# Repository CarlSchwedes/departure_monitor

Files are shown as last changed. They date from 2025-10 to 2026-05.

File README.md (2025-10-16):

# Departure Monitor
Day-to-day life in Germany’s capital, Berlin, can be quite chaotic and stressful from time to time.
That’s why a live departure monitor which automatically updates every minute can be an incredibly useful companion — showing you when the next train, bus, subway, or tram will arrive right in front of your house.

I often found myself quite bothered by constantly checking my phones' app to see when the next connection would arrive at my nearest station.
That led to the idea for Departure Monitor - a small DIY device that continuously displays real-time departure data from the public transport system.

With this ESP32-powered gadget, you will have up-to-date information for your preferred station at a glance.

<div style="text-align: center;">
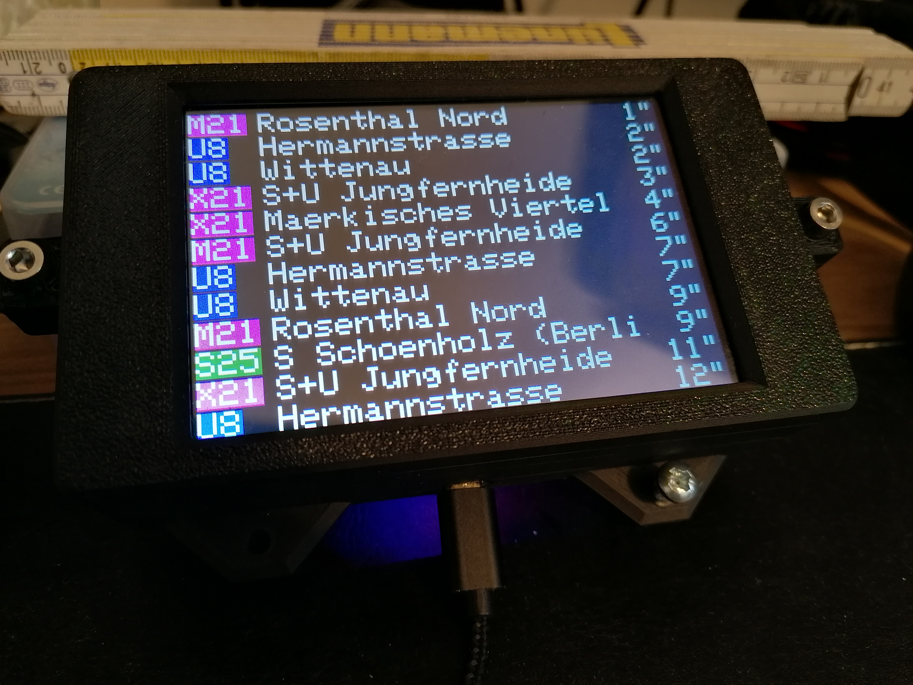
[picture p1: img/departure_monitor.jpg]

</div>

## Features
- Live Updates — Fetches real-time departure data every minute from the public VBB API
- Compact DIY Design — Built around an ESP32 microcontroller and a small display
- Open Source — Includes all models, print files, and source code
- Easy Setup — Simple to assemble and flash using the Arduino IDE
- Configurable — Adjust your station, preferred lines, and directions

# Repository Contents
- Fusion 360 model (.f3d)
- 3D print files (.stl, .3mf for BambuLab)
- Pin configuration and wiring diagram
- Source code for ESP32 (Arduino IDE)
- Images and assembly instructions

## Arduino IDE Setup:
- ArduinoJson 7.4.2
- TFT_eSPI 2.5.43
- ArduinoHttpClient 0.6.1

## TFT_eSPI lib
In ***Arduino\libraries*** path, file structure should look like the following:

TFT_eSPI\ ...
TFT_eSPI\User_Setup_Select.h

TFT_eSPI_Setups\mySetup27_ST7796_ESP32.h

## Pin Configuration
<div style="text-align: center;">
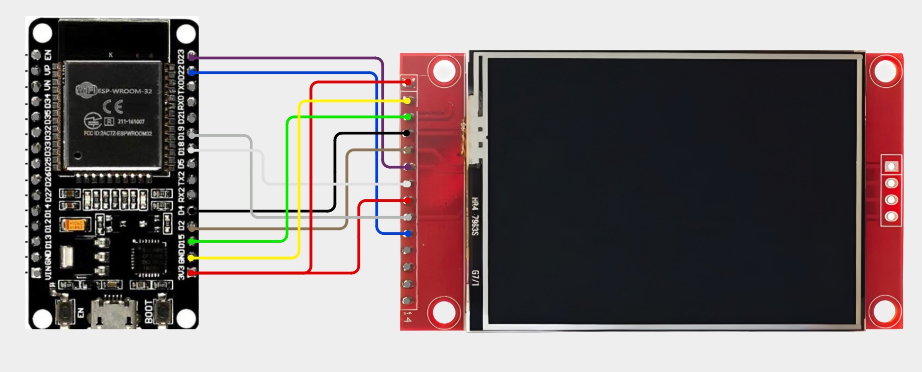
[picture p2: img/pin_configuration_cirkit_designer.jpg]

</div>

## Prepare API URL
Refer to the official [VBB API documentation](https://v6.vbb.transport.rest/api.html) to prepare your user specific api call.

```cpp
#define DEP_LIMIT 20 // define a dept limit, how many entries you want to fetch in one api call (limited to 100/min.)
```

```cpp
String apiURL = "https://v6.vbb.transport.rest/stops/900100003/departures?duration=60&lines=true&results=" + String(DEP_LIMIT);
```

For this api call I used ```GET /stops/:id/departures``` to get all departures at the stop/station.

- ```id: 900100003``` - ***S+U Alexanderplatz*** (https://v6.vbb.transport.rest/stops/900100003/departures)
- ```duration``` - in minutes for the next upcoming departures
- ```lines``` - returns stops/stations along the line when set to ```true```

## Hardware Parts:
- Display: 4" TFT SPI 480x320 ST7796S [display amazon](https://www.amazon.de/dp/B0CQ87KN3Q?ref=ppx_yo2ov_dt_b_fed_asin_title&th=1)

- ESP32 starter kit [esp32 kit amazon](https://www.amazon.de/dp/B0CTMQQ1W4?ref=ppx_yo2ov_dt_b_fed_asin_title)

- jumper cables: [cables short amazon](https://www.amazon.de/dp/B08HQ7K6M7?ref=ppx_yo2ov_dt_b_fed_asin_title)

<div style="text-align: center;">
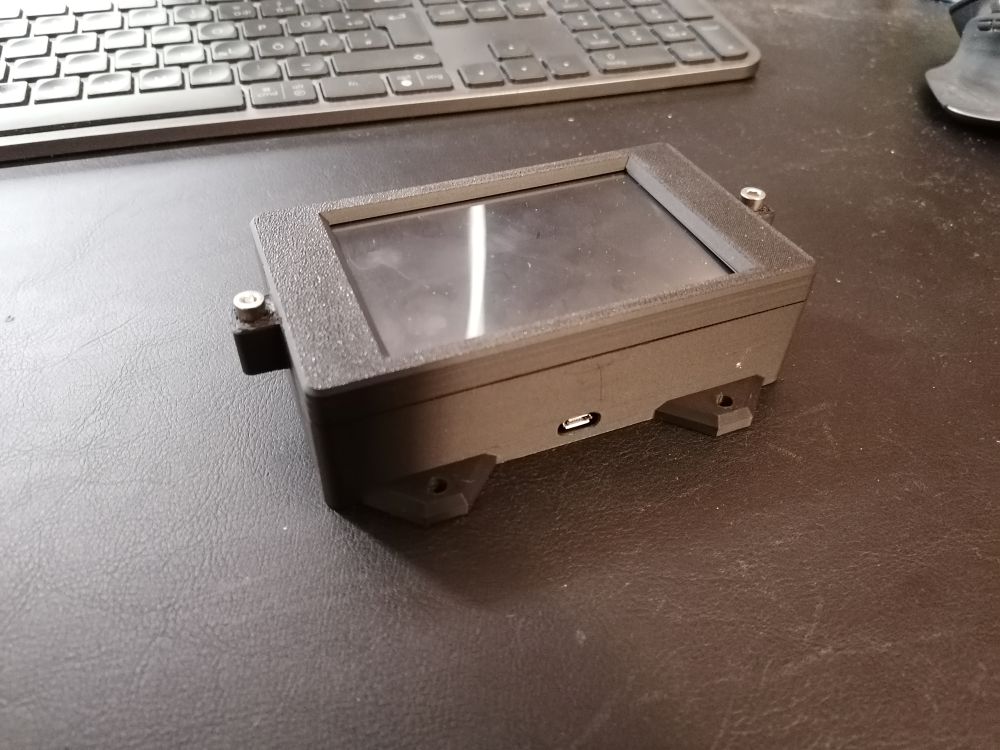
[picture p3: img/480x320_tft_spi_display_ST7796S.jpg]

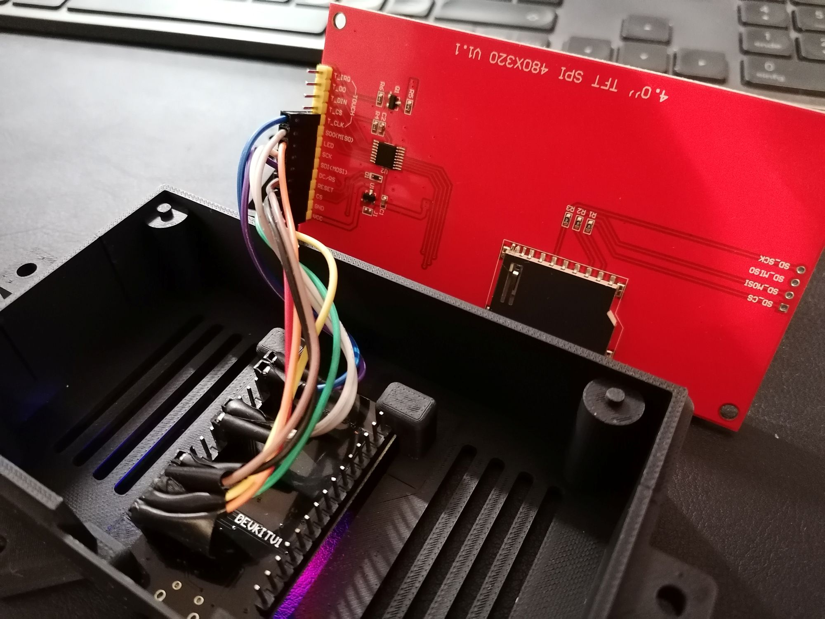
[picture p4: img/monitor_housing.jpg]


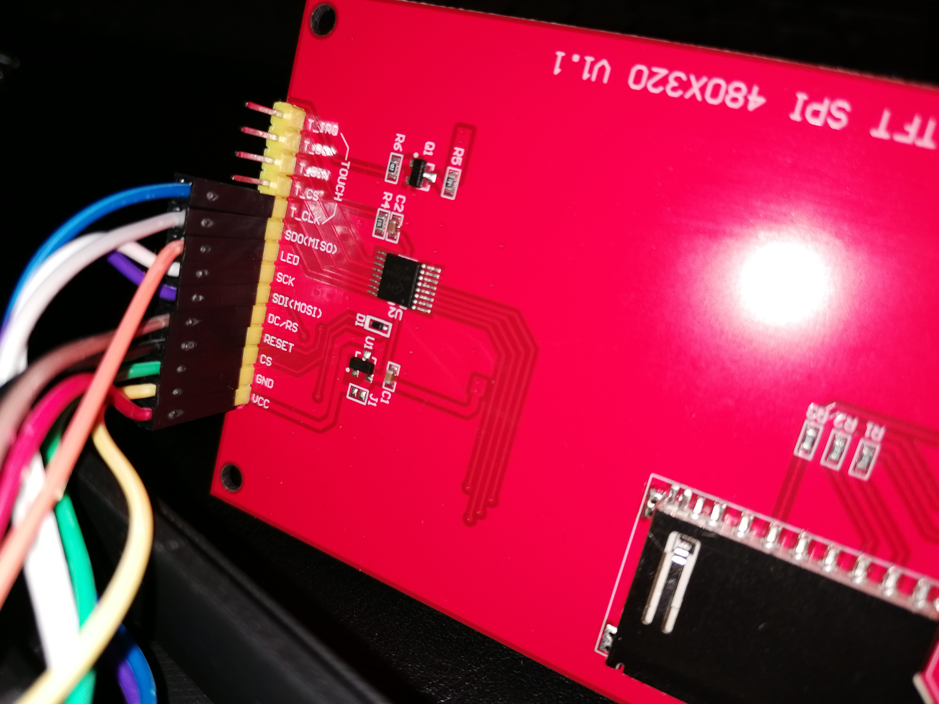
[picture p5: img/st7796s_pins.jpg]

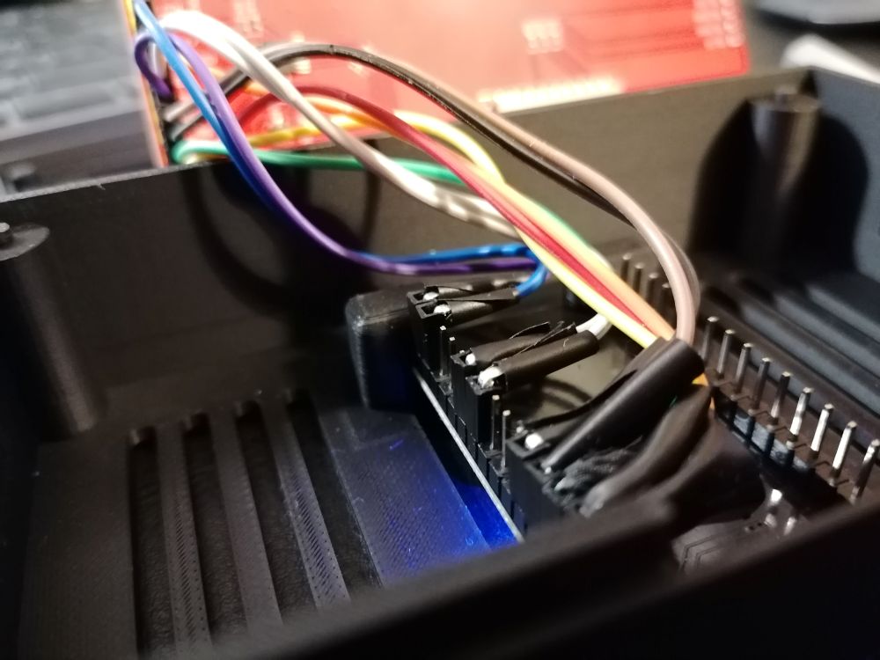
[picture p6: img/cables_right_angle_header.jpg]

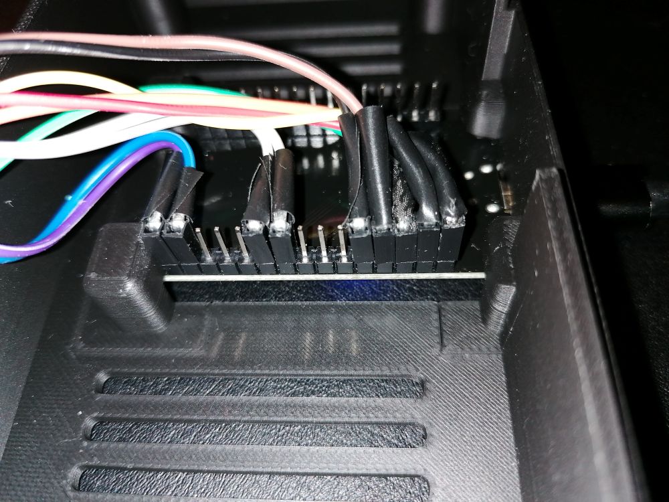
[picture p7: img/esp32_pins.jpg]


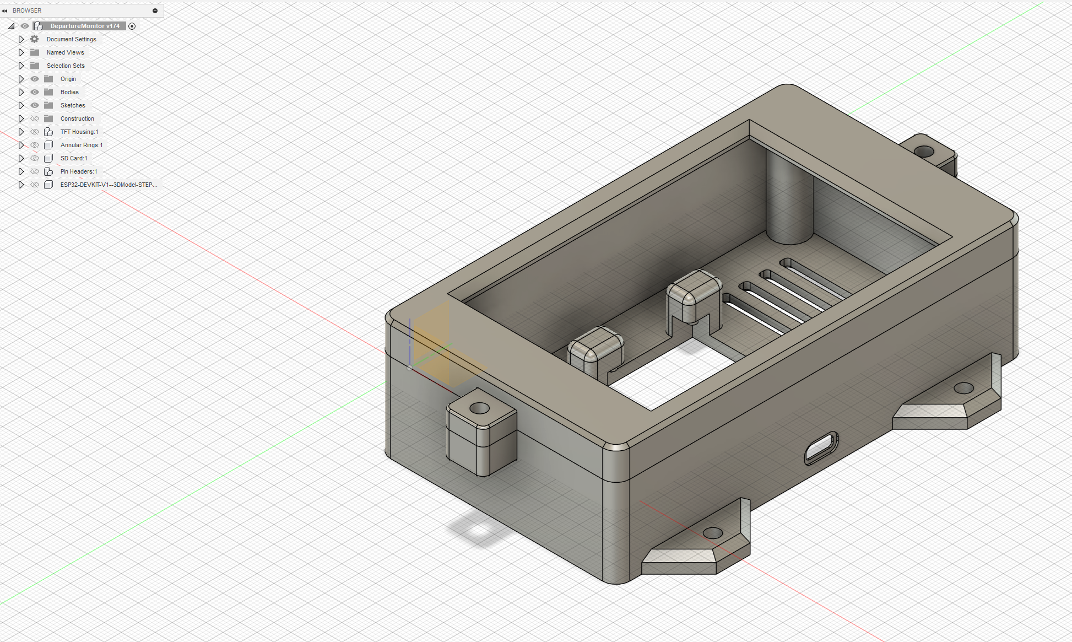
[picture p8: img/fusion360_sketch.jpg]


 The housing has been printed with a bambulab A1 0.4 mm print nozzle and PLA standard filament. Layer height has been set to 0.12 mm which gave appropriate results.
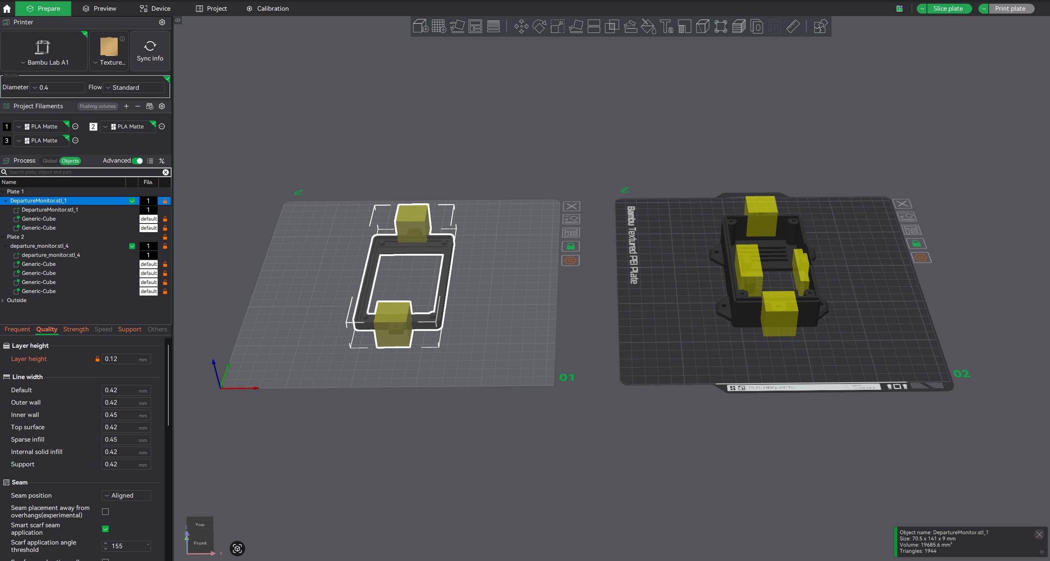
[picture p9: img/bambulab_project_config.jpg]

</div>

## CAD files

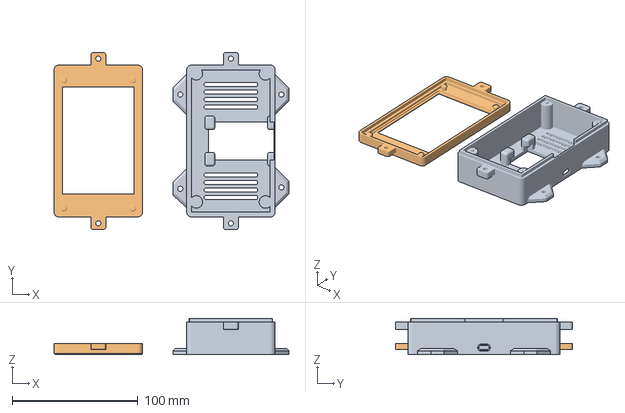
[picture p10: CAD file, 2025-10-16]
model/departure_monitor.3mf
187.0 x 141.0 x 29.0 mm
departure_monitor.stl_4
departure_monitor.stl_1

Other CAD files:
model/departure_monitor.stl

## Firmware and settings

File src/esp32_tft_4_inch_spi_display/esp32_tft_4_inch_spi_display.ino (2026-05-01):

#include <WiFi.h>
#include <WiFiClientSecure.h>
#include <HTTPClient.h>
#include <ArduinoJson.h>
#include <TFT_eSPI.h>
#include <time.h>

#define DEPARTURES_FETCH_LIMIT 20
#define JOURNEYS_FETCH_LIMIT 4
#define JOURNEYS_TRANSFERS_LIMIT 1
#define DEPARTURES_DISPLAY_LIMIT 11
#define JOURNEYS_DISPLAY_LIMIT 1
#define MAX_TRANSFER_TIME 10
#define MIN_TO_ARRIVE_THRESHOLD 3

bool serialPrintForDebugPurpose = false;

unsigned long lastFetchMs = 0UL;
unsigned long lastDisplayMs = 0UL;

// ====== WiFi credentials
const char* ssid = "";
const char* password = "";

// Configurable API endpoints
struct ApiConfig {
  String url;
  size_t jsonCapacity;
  int displayLimit;
};

// VBB API configurations
const ApiConfig apis[] = {
  { "https://v6.vbb.transport.rest/stops/900096458/departures?duration=60&remarks=false&results=" + String(DEPARTURES_FETCH_LIMIT), 32768, DEPARTURES_DISPLAY_LIMIT },  // departures
  { "https://v6.vbb.transport.rest/journeys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" + String(JOURNEYS_TRANSFERS_LIMIT) + "&via=900009203&remarks=false&verkehrsunternehmen=false&polyline=false&language=en&format=compact&results=" + String(JOURNEYS_FETCH_LIMIT), 65536, JOURNEYS_DISPLAY_LIMIT }  // journeys
};

const int NUM_APIS = sizeof(apis) / sizeof(apis[0]);

// Global data storage (fetched once per loop)
struct ApiData {
  int status = 0;                     // 1=valid, 0=fetch-ok, -1=json, -2=http
  bool stale = false;
  int httpErrorCode = 0;              // http status
  DynamicJsonDocument* temp = nullptr;
  DynamicJsonDocument* doc = nullptr;
  unsigned long lastSuccessMs = 0UL;
  bool INIT_FETCH_VALID = false;
};

ApiData apiData[NUM_APIS] = {};

TFT_eSPI tft = TFT_eSPI();

// Helper: Parse ISO string -> time_t
time_t parseIsoToTime(const String& isoTimeStr) {
  if (isoTimeStr.length() < 19) return (time_t)-1;
  
  struct tm t = {0};
  t.tm_year  = isoTimeStr.substring(0, 4).toInt() - 1900;
  t.tm_mon   = isoTimeStr.substring(5, 7).toInt() - 1;
  t.tm_mday  = isoTimeStr.substring(8, 10).toInt();
  t.tm_hour  = isoTimeStr.substring(11, 13).toInt();
  t.tm_min   = isoTimeStr.substring(14, 16).toInt();
  t.tm_sec   = isoTimeStr.substring(17, 19).toInt();
  t.tm_isdst = -1;
  
  return mktime(&t);
}


String timeToIsoString(time_t t) {
  struct tm tmTime;
  localtime_r(&t, &tmTime);

  char buf[25];  // "2026-04-24T13:05:00"
  strftime(buf, sizeof(buf), "%Y-%m-%iT%H:%M:%S", &tmTime);
  return String(buf);
}


// Get current time as time_t (cached)
time_t getCurrentTime() {
  struct tm nowTm;
  if (!getLocalTime(&nowTm)) {
    Serial.println("Failed to get current time");
    return (time_t)-999;
  }
  return mktime(&nowTm);
}


// Minutes from now -> target time
int getMinutesToDeparture(const String& isoTimeStr) {
  time_t arrival = parseIsoToTime(isoTimeStr);
  if (arrival < 0) return -999;
  
  time_t now = getCurrentTime();
  if (now < 0) return -999;
  
  return round(difftime(arrival, now) / 60.0);
}


// Minutes between two times
int getMinutesBetween(const String& startIsoStr, const String& endIsoStr) {
  time_t start = parseIsoToTime(startIsoStr);
  time_t end   = parseIsoToTime(endIsoStr);
  
  if (start < 0 || end < 0) return -999;
  
  return round(difftime(end, start) / 60.0);
}


String decodeUtf8(String input) {
  input.replace("\u00e4", "ae");
  input.replace("\u00f6", "oe");
  input.replace("\u00fc", "ue");
  input.replace("\u00c4", "Ae");
  input.replace("\u00d6", "Oe");
  input.replace("\u00dc", "Ue");
  input.replace("\u00df", "ss");

  for (int i = 0; i < input.length(); i++) {
    if (input[i] < 32 || input[i] > 126) input[i] = '?';
  }

  return input;
}


uint16_t getBackgroundColor(String product) {
  uint16_t color = TFT_BLACK;

  if (product == "bus")
    color = TFT_MAGENTA;
  else if (product == "suburban")
    color = TFT_DARKGREEN;
  else if (product == "subway")
    color = TFT_BLUE;
  else if (product == "tram")
    color = TFT_RED;
  else if (product == "ferry")
    color = TFT_SKYBLUE;

  return color;
} 


void showCountdownMessage(int seconds, const char* message) {
  for (int i = seconds; i >= 0; i--) {
    tft.fillRect(tft.width() / 4, tft.height() / 4, tft.width() * 3 / 4, tft.height() * 3 / 4, TFT_BLACK);
    String msg = String(message) + " " + String(i) + " sec...";
    tft.setTextColor(TFT_RED, TFT_BLACK);
    tft.setTextDatum(MC_DATUM);
    tft.drawString(msg, tft.width() / 2, tft.height() / 2);
    delay(1000);
  }
}


void displayError(const char* message) {
  tft.fillScreen(TFT_BLACK);
  tft.setTextSize(1);
  tft.setCursor(0, 0);
  tft.setTextColor(TFT_RED, TFT_BLACK);
  tft.println("Error:");
  tft.println(message);

  showCountdownMessage(3, "Restart in");
}


void displayWiFiOk() {
  tft.fillScreen(TFT_BLACK);
  tft.setTextSize(1);
  tft.setCursor(0, 0);
  tft.setTextColor(TFT_WHITE, TFT_BLACK);
  tft.println("WiFi Ok!");

  showCountdownMessage(10, "Loop over in");
}


void cleanupApiData(int i) {
    apiData[i].status = 0;
    apiData[i].stale = false;
    apiData[i].httpErrorCode = 0;
    apiData[i].INIT_FETCH_VALID = false;
    apiData[i].lastSuccessMs = 0UL;
    if (apiData[i].doc) {
      delete apiData[i].doc;
      apiData[i].doc = nullptr;
    }
    if (apiData[i].temp) {
      delete apiData[i].temp;
      apiData[i].temp = nullptr;
    }
}


template <typename... Args>
void serialPrintfDebug(const char* dbgMsg, Args... args) {
  if (serialPrintForDebugPurpose) {
    Serial.printf(dbgMsg, args...);
  }
}


void handleApiError(int apiIndex, int apiStatus, HTTPClient& http, WiFiClientSecure& client, int delayMs = 100) {
  serialPrintfDebug<int, int>("\t\t ERROR: API<%i> failed to fetch; STATUS: %i\n", apiIndex, apiStatus);
  apiData[apiIndex].status = apiStatus;
  http.end();
  client.stop();
  delay(delayMs);
}


// Fetch ALL APIs -> store in global apiData[]
void fetchApiData() {
  serialPrintfDebug("Fetching...\n");
  for (int i = 0; i < NUM_APIS; i++) {
    serialPrintfDebug<int>("API: %i\n", i);

    if (WiFi.status() != WL_CONNECTED) {
      WiFi.reconnect();
      delay(2000);
      if (WiFi.status() != WL_CONNECTED) 
        serialPrintfDebug("Failed to reconnect WiFi, restart!\n");
        ESP.restart();
    }

    for (int attempt = 0; attempt <= 2; attempt++) {
      serialPrintfDebug<int>("\t ATTEMPT: %i\n", attempt);

      // Fresh client EVERY TIME
      WiFiClientSecure client;
      client.setInsecure();
      client.setTimeout(10000);
      
      HTTPClient http;
      http.useHTTP10(true); // use HTTP/1.0 instead of default HTTP/1.1; HTTP/1.0 avoids trying to keep socket alive -> client typically sends Connection: close
      http.setReuse(false); // HTTPClient forced not to reuse TCP connection for next request; reduces bugs where ESP32 accidentally reuses a stale or wrong connection
      http.begin(client, apis[i].url);
      http.addHeader("User-Agent", "ESP32-Display/1.0");
      http.setTimeout(10000);

      unsigned long t = millis();
      int httpCode = http.GET();
      apiData[i].httpErrorCode = httpCode;
      serialPrintfDebug<unsigned long>("\t http.GET() took %lu ms\n", millis() - t);
      yield();  // Keep connection alive; prevents ESP32 watchdog resets
      serialPrintfDebug<int>("\t HTTP-Code GET: %i\n", httpCode);

      // ERROR Handling
      if (httpCode != HTTP_CODE_OK) {
        handleApiError(i, -2, http, client);
        continue;
      }

      t = millis();
      String payload = http.getString();
      serialPrintfDebug<unsigned long>("\t http.getString() took %lu ms\n", millis() - t);
      //yield();  // Keep connection alive; prevents ESP32 watchdog resets
      serialPrintfDebug<int>("\t Payload bytes: %i\n", payload.length());
      serialPrintfDebug<int>("\t Expected bytes: %i\n", http.getSize());
      serialPrintfDebug<const char*>("\t Payload preview: %.60s\n", payload.c_str());
      
      // ERROR Handling
      if (payload.length() == 0) {
        serialPrintfDebug("\t\t ERROR: Empty payload (EmptyInput likely)\n");
        handleApiError(i, -1, http, client);
        continue;
      }

      // ERROR Handling
      if (payload[0] != '{' && payload[0] != '[') {
        serialPrintfDebug("\t\t ERROR: Payload JSON must start with '{' or '['\n");
        handleApiError(i, -1, http, client);
        continue;
      }

      apiData[i].temp = new DynamicJsonDocument(apis[i].jsonCapacity);
      DeserializationError error = deserializeJson(*apiData[i].temp, payload);

      if (error) {
        serialPrintfDebug<const char*>("\t ERROR: deserializeJson: %s\n", error.c_str());
        handleApiError(i, -1, http, client);
        continue;
      }

      if (serialPrintForDebugPurpose && !error) {
        String preview;
        serializeJson(*apiData[i].temp, preview);
        serialPrintfDebug<const char*>("\t JSON preview: %.60s\n", preview.c_str());
        serialPrintfDebug<int>("\t JSON length: %i\n", preview.length());
      }

      apiData[i].status = 0;
      serialPrintfDebug<int>("\t Status-Code: %i\n", apiData[i].status);

      http.end();
      client.stop();

      delay(500);
      break;
    }
  }
}


bool validateDeparturesDoc(DynamicJsonDocument& doc) {
  serialPrintfDebug("\t Validating departures...\n");
    if (doc.isNull()) {
    serialPrintfDebug("\t ERROR: DynamicJsonDocument doc is NULL\n");
    return false;
  }

  if (!doc["departures"].is<JsonArray>()) {
    serialPrintfDebug("\t ERROR: Departures not of type <JsonArray>\n");
    return false;
  }

  JsonArray deps = doc["departures"].as<JsonArray>();
  if (deps.isNull()) {
    serialPrintfDebug("\t ERROR: Departures <JsonArray> is NULL\n");
    return false;
  }
  
  if (deps.size() == 0) {
    serialPrintfDebug("\t ERROR: Departures <JsonArray> size 0\n");
    return false;
  }

  JsonObject first = deps[0];
  if (first.isNull()) {
    serialPrintfDebug("\t ERROR: Departures <JsonObject> deps[0] is NULL\n");
    return false;
  }
  if (!first["when"].is<const char*>()) {
    serialPrintfDebug("\t ERROR: Departures <JsonObject> deps[0][\"when\"] is not of type <const char*>\n");
    return false;
  }
  if (!first["line"]["name"].is<const char*>()) {
    serialPrintfDebug("\t ERROR: Departures <JsonObject> deps[0][\"line\"][\"name\"] is not of type <const char*>\n");
    return false;
  }
  if (!first["direction"].is<const char*>()) {
    serialPrintfDebug("\t ERROR: Departures <JsonObject> deps[0][\"direction\"] is not of type <const char*>\n");
    return false;
  }

  return true;
}


bool validateJourneysDoc(DynamicJsonDocument& doc) {
  serialPrintfDebug("\t Validating journeys...\n");
  if (doc.isNull()) {
    serialPrintfDebug("\t ERROR: DynamicJsonDocument doc is NULL\n");
    return false;
  }

  if (!doc["journeys"].is<JsonArray>()) {
    serialPrintfDebug("\t ERROR: Journeys not of type <JsonArray>\n");
    return false;
  }

  JsonArray journeys = doc["journeys"].as<JsonArray>();
  if (journeys.isNull()) {
    serialPrintfDebug("\t ERROR: Journeys <JsonArray> is NULL\n");
    return false;
  }
  if (journeys.size() == 0) {
    serialPrintfDebug("\t ERROR: Journeys <JsonArray> size 0\n");
    return false;
  }

  JsonObject first = journeys[0];
  if (first.isNull()) {
    serialPrintfDebug("\t ERROR: Journeys <JsonObject> journeys[0] is NULL\n");
    return false;
  }
  if (!first["legs"].is<JsonArray>()) {
    serialPrintfDebug("\t ERROR: Journeys <JsonObject> journeys[0][\"legs\"] is not of type <JsonArray>\n");
    return false;
  }

  JsonArray legs = first["legs"].as<JsonArray>();
  if (legs.size() < 1) {
    serialPrintfDebug("\t ERROR: Journeys journeys[0][\"legs\"] size 0\n");
    return false;
  }

  return true;
}


bool validateApiDoc(int apiIndex, DynamicJsonDocument& doc) {
  switch (apiIndex) {
    case 0: return validateDeparturesDoc(doc);
    case 1: return validateJourneysDoc(doc);
    default: return false;
  }
}


void validateApiData() {
  serialPrintfDebug("Validating...\n");
  for (int i = 0; i < NUM_APIS; i++) {

    if (i == 0 && apiData[i].status == 0 && serialPrintForDebugPurpose) {
      JsonArray deps = (*apiData[0].temp)["departures"].as<JsonArray>();
      String preview;
      serializeJson(deps, preview);
      serialPrintfDebug<int, int, const char*>("\t DOC<%i>: %i items: %.80s\n", i, deps.size(), preview.c_str());
    }
    if (i == 1 && apiData[i].status == 0 && serialPrintForDebugPurpose) {
      JsonArray jrny = (*apiData[1].temp)["journeys"].as<JsonArray>();
      String preview;
      serializeJson(jrny, preview);
      serialPrintfDebug<int, int, const char*>("\t DOC<%i>: %i items: %.80s\n", i, jrny.size(), preview.c_str());
    }

    if (apiData[i].status == 0 && validateApiDoc(i, (*apiData[i].temp))) {
      apiData[i].INIT_FETCH_VALID = true;
      apiData[i].status = 1;
      delete apiData[i].doc;
      apiData[i].doc = new DynamicJsonDocument(*apiData[i].temp);

      delete apiData[i].temp;
      apiData[i].temp = nullptr;
      apiData[i].lastSuccessMs = millis(); // set age of successful fetch to current time

      if (i == 0 && serialPrintForDebugPurpose) {
        JsonArray deps = (*apiData[0].doc)["departures"].as<JsonArray>();
        String preview;
        serializeJson(deps, preview);
        serialPrintfDebug<int, int, const char*>("\t\t DOC<%i>: %i items: %.80s\n", i, deps.size(), preview.c_str());
      }
      if (i == 1 && serialPrintForDebugPurpose) {
        JsonArray journeys = (*apiData[1].doc)["journeys"].as<JsonArray>();
        String preview;
        serializeJson(journeys, preview);
        serialPrintfDebug<int, int, const char*>("\t\t DOC<%i>: %i items: %.80s\n", i, journeys.size(), preview.c_str());
      }

      serialPrintfDebug<int>("\t API<%i> Valid Json; LastSuccess: %lu ms\n", i, apiData[i].lastSuccessMs);
    }
    else {
      delete apiData[i].temp;
      apiData[i].temp = nullptr;
      serialPrintfDebug<int>("\t API<%i> Invalid Json; LastSuccess: %lu ms; Age: %i ms\n", i, apiData[i].lastSuccessMs, millis() - apiData[i].lastSuccessMs);
    }
    serialPrintfDebug("\t --------\n");
  }
}


void staleJsonDeparturesDoc(unsigned long ageMs) {
  JsonArray deps = (*apiData[0].doc)["departures"].as<JsonArray>();

  serialPrintfDebug("\t\t Adjusted mins: ");
  for (JsonObject dep : deps) {
    time_t correctedTime = parseIsoToTime(dep["when"].as<String>()) - (ageMs / 60000);
    dep["when"] = timeToIsoString(correctedTime);

    serialPrintfDebug("depWhen: %s\n", dep["when"].as<String>());

    serialPrintfDebug<int>("%i ", getMinutesToDeparture(dep["when"].as<String>()));
  }
  serialPrintfDebug("\n");
}


void staleJsonJourneysDoc(unsigned long ageMs) {
  JsonArray journeys = (*apiData[1].doc)["journeys"].as<JsonArray>();

  serialPrintfDebug("\t\t Adjusted mins: ");
  for (JsonObject jrny : journeys) {
    time_t correctedTime = parseIsoToTime(jrny["legs"][0]["departure"].as<String>()) - (ageMs / 60000);
    jrny["legs"][0]["departure"] = timeToIsoString(correctedTime);

    serialPrintfDebug("jrnyLegsDepartures: %s\n", jrny["legs"][0]["departure"].as<String>());

    serialPrintfDebug<int>("%i ", getMinutesToDeparture(jrny["legs"][0]["departure"].as<String>()));
  }
  serialPrintfDebug("\n");
}


void handleStaleJSON() {
  serialPrintfDebug("Handling stale json...\n");
  for (int i = 0; i < NUM_APIS; i++) {
    if (apiData[i].INIT_FETCH_VALID) {
      unsigned long ageMs = millis() - apiData[i].lastSuccessMs;

      serialPrintfDebug<int, int>("\t API<%i>-STATUS: %i\n", i, apiData[i].status);
      serialPrintfDebug<unsigned long>("\t\t age: %lu\n", ageMs);

      if (apiData[i].status != 1 && ageMs > 60000 && ageMs < 180000) { // handle stale json data (of current invalid fetch)
        apiData[i].stale = true;
        serialPrintfDebug("\t\t Updating with STALE-JSON...\n");
        //if (i == 0) staleJsonDeparturesDoc(ageMs);
        //if (i == 1) staleJsonJourneysDoc(ageMs);
      }
      else if (ageMs > 180000) {
        ESP.restart();  // Instant full reset
        //cleanupApiData(i);
        //serialPrintfDebug("\t\t Cleaned and reseted API struct from outdated JSON!\n");
      }
      else if (apiData[i].status == 1) {
        apiData[i].stale = false;
        serialPrintfDebug("\t\t Object not stale. Continue...\n");
      }
    }
  }
}


// Display DEPARTURES (API 0)
void displayDepartures() {

  if (!apiData[0].doc) {
    tft.println("No departures ...");
    return;
  }
  
  JsonArray deps = (*apiData[0].doc)["departures"];
  serialPrintfDebug<int>("\t -> Departures array size: %i\n", deps.size());  // Debug!
  
  // if (deps.isNull()) return;
  
  // if (deps.isNull() || deps.size() == 0) {
  //   tft.println("No departures found ...");
  //   return;
  // }

  uint16_t tft_color = apiData[0].stale ? TFT_LIGHTGREY : TFT_WHITE;

  int count = 0;
  for (JsonObject dep : deps) {
    if (count >= apis[0].displayLimit) break;
    
    String line = dep["line"]["name"].as<String>();
    String direction = dep["direction"].as<String>();
    String product = dep["line"]["product"].as<String>();
    int min_to_arrive = getMinutesToDeparture(dep["when"].as<String>());
    
    if (min_to_arrive < MIN_TO_ARRIVE_THRESHOLD) continue;
    
    uint16_t bg = getBackgroundColor(product);
    tft.setTextColor(TFT_WHITE, bg);
    tft.drawString(line, 0, count * (tft.fontHeight() + 3));
    
    direction = decodeUtf8(direction).substring(0, 19);
    while (direction.length() < 19) direction += " ";
    
    String delta = (min_to_arrive <= 0) ? "now" : String(min_to_arrive) + "'";
    while (delta.length() < 4) delta = " " + delta;
    
    tft.setTextColor(tft_color, TFT_BLACK);
    tft.drawString(direction + delta, 65, count * (tft.fontHeight() + 3));
    count++;
  }
  
  if (count == 0) tft.println("No departures ...");
}


// Display JOURNEYS (API 1)
void displayJourneys() {
  int count = DEPARTURES_DISPLAY_LIMIT;
  // draw thin separator line
  tft.drawLine(0, (count * (tft.fontHeight() + 3)) - 2, tft.width() - 1, (count * (tft.fontHeight() + 3)) - 2, TFT_WHITE);

  if (!apiData[1].doc) {
    tft.drawString("No journeys data ...", 0, DEPARTURES_DISPLAY_LIMIT * (tft.fontHeight() + 3));
    return;
  }
  
  JsonArray journeys = (*apiData[1].doc)["journeys"];
  serialPrintfDebug<int>("\t -> Journeys array size: %i\n", journeys.size());  // Debug!

  // if (journeys.isNull() || journeys.size() == 0) {
  //   tft.drawString("No journeys found ...", 0, DEPARTURES_DISPLAY_LIMIT * (tft.fontHeight() + 3));
  //   return;
  // }

  uint16_t tft_color = apiData[1].stale ? TFT_LIGHTGREY : TFT_WHITE;

  for (JsonObject jrny : journeys) {

    String line0 = jrny["legs"][0]["line"]["name"].as<String>();
    String direction0 = "HER";
    String product0 = jrny["legs"][0]["line"]["product"].as<String>();

    String line2 = jrny["legs"][2]["line"]["name"].as<String>();
    String destination = jrny["legs"][2]["destination"]["name"].as<String>();
    String product2 = jrny["legs"][2]["line"]["product"].as<String>();

    int min_to_arrive = getMinutesToDeparture(jrny["legs"][0]["departure"].as<String>());
    int transfer_time = getMinutesBetween(jrny["legs"][0]["arrival"].as<String>(), jrny["legs"][2]["departure"].as<String>());

    uint16_t background0 = getBackgroundColor(product0);
    uint16_t background2 = getBackgroundColor(product2);

    if (min_to_arrive >= MIN_TO_ARRIVE_THRESHOLD && transfer_time <= MAX_TRANSFER_TIME) {
      tft.setTextColor(TFT_WHITE, background0);
      tft.drawString(line0, 0, count * (tft.fontHeight() + 3));
      direction0 += " -> ";

      tft.setTextColor(TFT_WHITE, background2);
      tft.drawString(line2, 190, count * (tft.fontHeight() + 3));
      if (destination.length() > 8) destination = destination.substring(0, 8);

      while ((direction0.length()+line2.length()+destination.length()) < 17) destination += " ";

      String delta_time = (min_to_arrive == 0) ? "now" : String(min_to_arrive) + "\'";
      while (delta_time.length() < 4) delta_time = " " + delta_time;

      String description = decodeUtf8(direction0);
      tft.setTextColor(tft_color, TFT_BLACK);
      tft.drawString(description, 65, count * (tft.fontHeight() + 3));

      description = decodeUtf8(destination) + delta_time;
      tft.setTextColor(tft_color, TFT_BLACK);
      tft.drawString(description, 260, count * (tft.fontHeight() + 3));

      count++;
    }

    if (count >= (DEPARTURES_DISPLAY_LIMIT+1)) 
      break;
  }

  if (count == DEPARTURES_DISPLAY_LIMIT) {
    tft.setTextColor(TFT_WHITE, TFT_BLACK);
    tft.drawString("No journeys at the time ...", 0, count * (tft.fontHeight() + 3));
  }
}


// Display ALL data (calls individual displays)
void displayAllData() {
  tft.fillScreen(TFT_BLACK);
  tft.setTextDatum(TL_DATUM);
  tft.setTextSize(3);
  tft.setCursor(0, 0);

  serialPrintfDebug("Displaying...\n");

  displayDepartures();
  displayJourneys();
}
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
void loop() {
  unsigned long now = millis();
  
  // Fetch APIs every 30s
  if (now - lastFetchMs >= 30000) {
    fetchApiData();    // Fetch ALL APIs once
    validateApiData(); // Validate JSON objects
    handleStaleJSON(); // In case fetch failed
    lastFetchMs = now;
  }
  
  // Redraw every 60s (uses latest data)
  if (now - lastDisplayMs >= 60000) {
    displayAllData();  // Display everything
    lastDisplayMs = now;
  }
  
  serialPrintfDebug<int, int, int>("\nFree heap: %d/%d; [%d%% usage]\n", ESP.getFreeHeap(), ESP.getHeapSize(), (1.0-(ESP.getFreeHeap()/(float)ESP.getHeapSize()))*100.0);
  serialPrintfDebug("--------\n");

  delay(15000);
}

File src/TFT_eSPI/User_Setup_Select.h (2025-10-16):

// This header file contains a list of user setup files and defines which one the
// compiler uses when the IDE performs a Verify/Compile or Upload.
//
// Users can create configurations for different boards and TFT displays.
// This makes selecting between hardware setups easy by "uncommenting" one line.

// The advantage of this hardware configuration method is that the examples provided
// with the library should work with immediately without any other changes being
// needed. It also improves the portability of users sketches to other hardware
// configurations and compatible libraries.
//
// Create a shortcut to this file on your desktop to permit quick access for editing.
// Re-compile and upload after making and saving any changes to this file.

// Example User_Setup files are stored in the "User_Setups" folder. These can be used
// unmodified or adapted for a particular hardware configuration.

#ifndef USER_SETUP_LOADED //  Lets PlatformIO users define settings in
                          //  platformio.ini, see notes in "Tools" folder.

///////////////////////////////////////////////////////
//   User configuration selection lines are below    //
///////////////////////////////////////////////////////

// Only ONE line below should be uncommented to define your setup.  Add extra lines and files as needed.

//#include <User_Setup.h>           // Default setup is root library folder
#include <../TFT_eSPI_Setups/mySetup27_ST7796_ESP32.h>           // Default setup is root library folder


//#include <User_Setups/Setup1_ILI9341.h>  // Setup file for ESP8266 configured for my ILI9341
//#include <User_Setups/Setup2_ST7735.h>   // Setup file for ESP8266 configured for my ST7735
//#include <User_Setups/Setup3_ILI9163.h>  // Setup file for ESP8266 configured for my ILI9163
//#include <User_Setups/Setup4_S6D02A1.h>  // Setup file for ESP8266 configured for my S6D02A1
//#include <User_Setups/Setup5_RPi_ILI9486.h>        // Setup file for ESP8266 configured for my stock RPi TFT
//#include <User_Setups/Setup6_RPi_Wr_ILI9486.h>     // Setup file for ESP8266 configured for my modified RPi TFT
//#include <User_Setups/Setup7_ST7735_128x128.h>     // Setup file for ESP8266 configured for my ST7735 128x128 display
//#include <User_Setups/Setup8_ILI9163_128x128.h>    // Setup file for ESP8266 configured for my ILI9163 128x128 display
//#include <User_Setups/Setup9_ST7735_Overlap.h>     // Setup file for ESP8266 configured for my ST7735
//#include <User_Setups/Setup10_RPi_touch_ILI9486.h> // Setup file for ESP8266 configured for ESP8266 and RPi TFT with touch

//#include <User_Setups/Setup11_RPi_touch_ILI9486.h> // Setup file configured for ESP32 and RPi TFT with touch
//#include <User_Setups/Setup12_M5Stack_Basic_Core.h>// Setup file for the ESP32 based M5Stack (Basic Core only)
//#include <User_Setups/Setup13_ILI9481_Parallel.h>  // Setup file for the ESP32 with parallel bus TFT
//#include <User_Setups/Setup14_ILI9341_Parallel.h>  // Setup file for the ESP32 with parallel bus TFT
//#include <User_Setups/Setup15_HX8357D.h>           // Setup file for ESP8266 configured for HX8357D
//#include <User_Setups/Setup16_ILI9488_Parallel.h>  // Setup file for the ESP32 with parallel bus TFT
//#include <User_Setups/Setup17_ePaper.h>            // Setup file for ESP8266 and any Waveshare ePaper display
//#include <User_Setups/Setup18_ST7789.h>            // Setup file for ESP8266 configured for ST7789

//#include <User_Setups/Setup19_RM68140_Parallel.h>	 // Setup file configured for RM68140 with parallel bus

//#include <User_Setups/Setup20_ILI9488.h>           // Setup file for ESP8266 and ILI9488 SPI bus TFT
//#include <User_Setups/Setup21_ILI9488.h>           // Setup file for ESP32 and ILI9488 SPI bus TFT

//#include <User_Setups/Setup22_TTGO_T4.h>           // Setup file for ESP32 and TTGO T4 version 1.2
//#include <User_Setups/Setup22_TTGO_T4_v1.3.h>      // Setup file for ESP32 and TTGO T4 version 1.3
//#include <User_Setups/Setup23_TTGO_TM.h>           // Setup file for ESP32 and TTGO TM ST7789 SPI bus TFT
//#include <User_Setups/Setup24_ST7789.h>            // Setup file for DSTIKE/ESP32/ESP8266 configured for ST7789 240 x 240
//#include <User_Setups/Setup25_TTGO_T_Display.h>    // Setup file for ESP32 and TTGO T-Display ST7789V SPI bus TFT
//#include <User_Setups/Setup26_TTGO_T_Wristband.h>  // Setup file for ESP32 and TTGO T-Wristband ST7735 SPI bus TFT

//#include <User_Setups/Setup27_RPi_ST7796_ESP32.h>    // ESP32   RPi MHS-4.0 inch Display-B
//#include <User_Setups/Setup28_RPi_ST7796_ESP8266.h>  // ESP8266 RPi MHS-4.0 inch Display-B

//#include <User_Setups/Setup29_ILI9341_STM32.h>          // Setup for Nucleo board
//#include <User_Setups/Setup30_ILI9341_Parallel_STM32.h> // Setup for Nucleo board and parallel display
//#include <User_Setups/Setup31_ST7796_Parallel_STM32.h>  // Setup for Nucleo board and parallel display
//#include <User_Setups/Setup32_ILI9341_STM32F103.h>      // Setup for "Blue/Black Pill"

//#include <User_Setups/Setup33_RPi_ILI9486_STM32.h>      // Setup for Nucleo board

//#include <User_Setups/Setup34_ILI9481_Parallel_STM32.h> // Setup for Nucleo board and parallel display
//#include <User_Setups/Setup35_ILI9341_STM32_Port_Bus.h> // Setup for STM32 port A parallel display

//#include <User_Setups/Setup36_RPi_touch_ST7796.h>      // Setup file configured for ESP32 and RPi ST7796 TFT with touch

//#include <User_Setups/Setup42_ILI9341_ESP32.h>           // Setup file for ESP32 and SPI ILI9341 240x320
//#include <User_Setups/Setup43_ST7735.h>            // Setup file for ESP8266 & ESP32 configured for my ST7735S 80x160
//#include <User_Setups/Setup44_TTGO_CameraPlus.h>   // Setup file for ESP32 and TTGO T-CameraPlus ST7789 SPI bus TFT    240x240
//#include <User_Setups/Setup45_TTGO_T_Watch.h>      // Setup file for ESP32 and TTGO T-Watch ST7789 SPI bus TFT  240x240
//#include <User_Setups/Setup46_GC9A01_ESP32.h>      // Setup file for ESP32 and GC9A01 SPI bus TFT  240x240

//#include <User_Setups/Setup47_ST7735.h>            // Setup file for ESP32 configured for ST7735 128 x 128 animated eyes

//#include <User_Setups/Setup50_SSD1963_Parallel.h>  // Setup file for ESP32 and SSD1963 TFT display

//#include <User_Setups/Setup51_LilyPi_ILI9481.h>    // Setup file for LilyGo LilyPi with ILI9481 display
//#include <User_Setups/Setup52_LilyPi_ST7796.h>     // Setup file for LilyGo LilyPi with ST7796 display

//#include <User_Setups/Setup60_RP2040_ILI9341.h>              // Setup file for RP2040 with SPI ILI9341
//#include <User_Setups/Setup61_RP2040_ILI9341_PIO_SPI.h>      // Setup file for RP2040 with PIO SPI ILI9341
//#include <User_Setups/Setup62_RP2040_Nano_Connect_ILI9341.h> // Setup file for RP2040 with SPI ILI9341

//#include <User_Setups/Setup66_Seeed_XIAO_Round.h>     // Setup file for Seeed XIAO with GC9A01 240x240
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

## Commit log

2025-10-30 fix single quote symbol instead of double quotes for minutes
    [esp32_tft_4_inch_spi_display.ino]
2026-02-08 update code structure esp32
2026-04-22 clean up script, improved runtime stability
    [esp32_tft_4_inch_spi_display.ino]
